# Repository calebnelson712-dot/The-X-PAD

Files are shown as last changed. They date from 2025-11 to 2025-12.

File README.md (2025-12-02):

# The-X-PAD
A  Seeed Studio XIAO RP2040 based macropad within 100 by 100

X-PAD is a custom macropad that has:

- 16 Hotswappable, MX Style Keys
- Per-key SK6812 RGB Baclight
- Based off of the Seeed Studio XIAO RP2040
- 2 Rotary Encoders
- 0.91" OLED Display
- Customizable Firmware
- A custom 3D-Printed Case
- And more!

------ 

# Images

## PCB


## Schematic






## 3D CAD
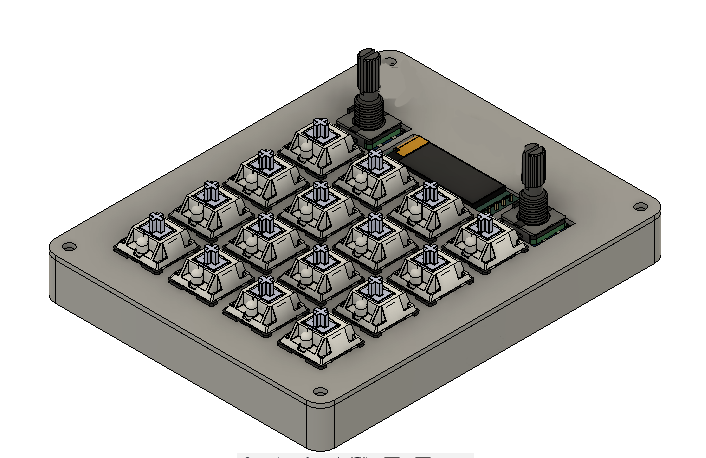
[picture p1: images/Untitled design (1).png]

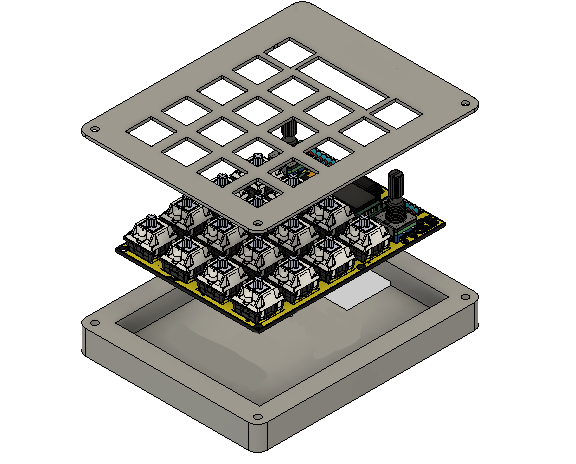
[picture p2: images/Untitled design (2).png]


# Bill Of Materials
Here's the BOM for my macropad:
| Name | Quantity |
|--- |---|
| Seeed Studio XIAO RP2040 | 1 |
| MCP23017 I2C I/O Expander | 1 |
| BSS138 MOSFET | 1 |
| 1N4148 Diode (Through-hole) | 16 |
| MX-Style Switch | 16 |
| Kailh MX-Style Hotswap Socket | 16 |
| Blank DSA Keycap (White) | 16 |
| EC11 With Switch | 2 |
| SK6812 MINI-E RGB LED | 16 |
| 0.1uF 0805 Ceramic Capacitor | 16 |
| 10kΩ 0805 Resistor | 4 |
| 0.91" OLED I2C Display | 1 |
| M3x16mm Screw | - |
| M3x5mx4mm Heatset Insert | - |
| 3D Printed Case (2 Parts) | 1 |
| Main PCB | MOQ: 5 |

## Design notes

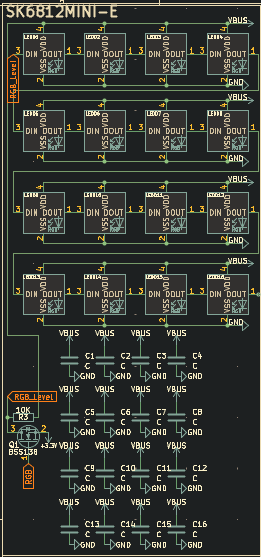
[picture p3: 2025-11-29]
images/RGB.png

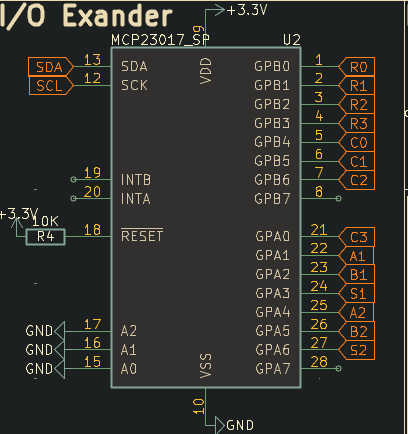
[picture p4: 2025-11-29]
images/Expander.png

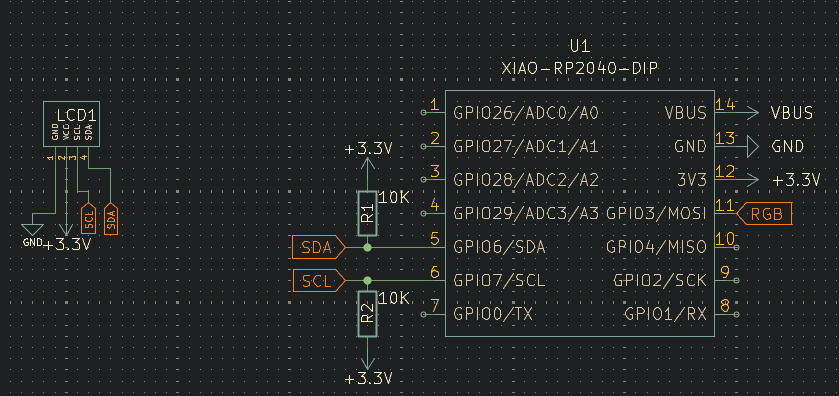
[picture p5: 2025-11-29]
images/OLED and XIAO.png

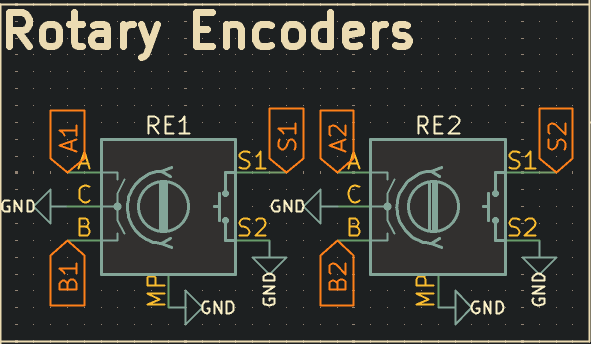
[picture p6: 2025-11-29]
images/Encoders.png

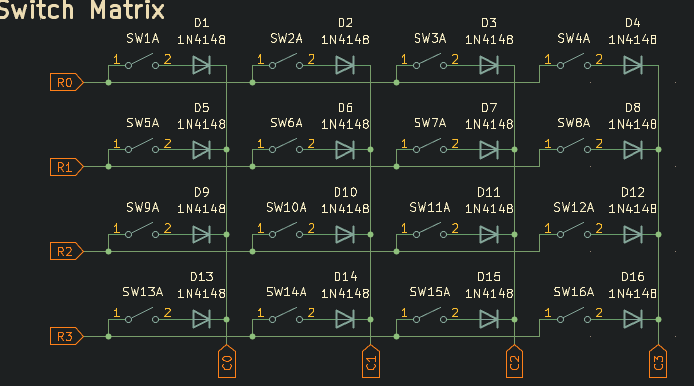
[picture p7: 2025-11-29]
images/Switch Matrix.png

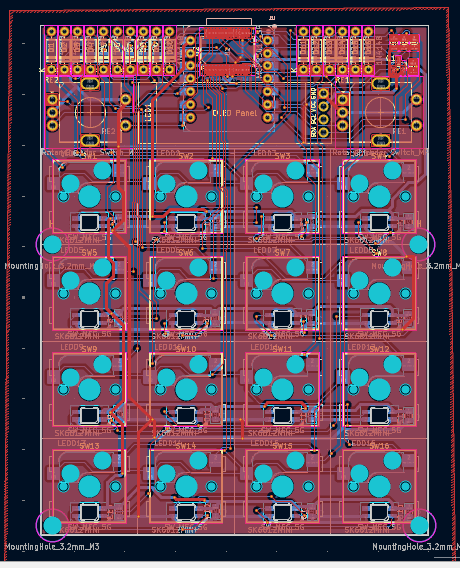
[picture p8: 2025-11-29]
images/PCB.png

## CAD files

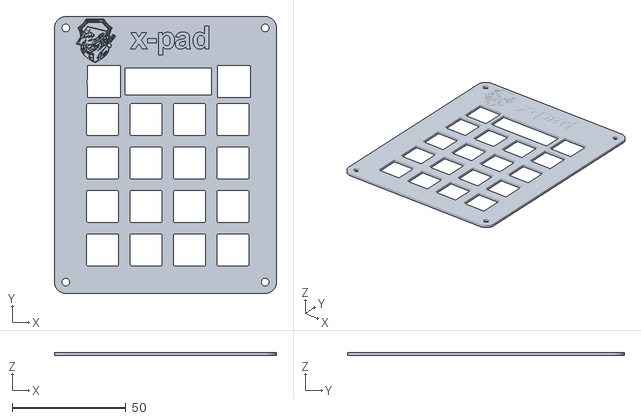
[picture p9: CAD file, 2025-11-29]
CASE/Top OF X-PAD.stl
97.4 x 121.5 x 1.50

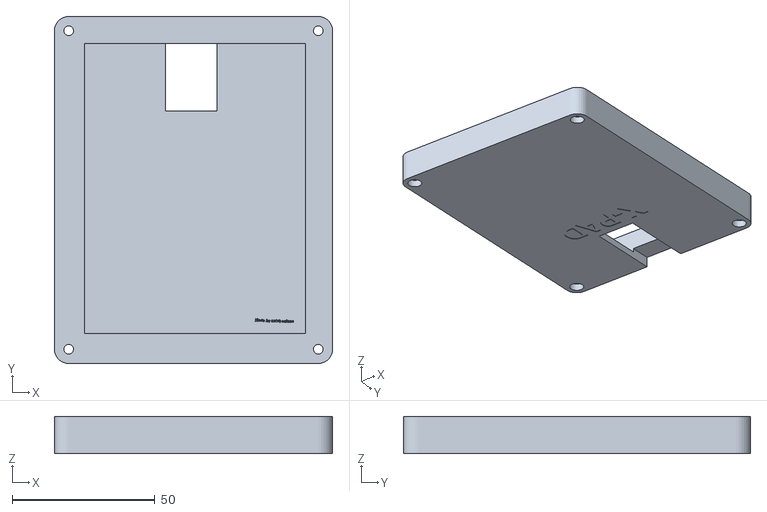
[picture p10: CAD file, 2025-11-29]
CASE/Bottom of x-pad.stl
97.4 x 121.5 x 13.0

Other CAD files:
production/Top of x-pad.step.step
production/Bottom of x-pad.step.step

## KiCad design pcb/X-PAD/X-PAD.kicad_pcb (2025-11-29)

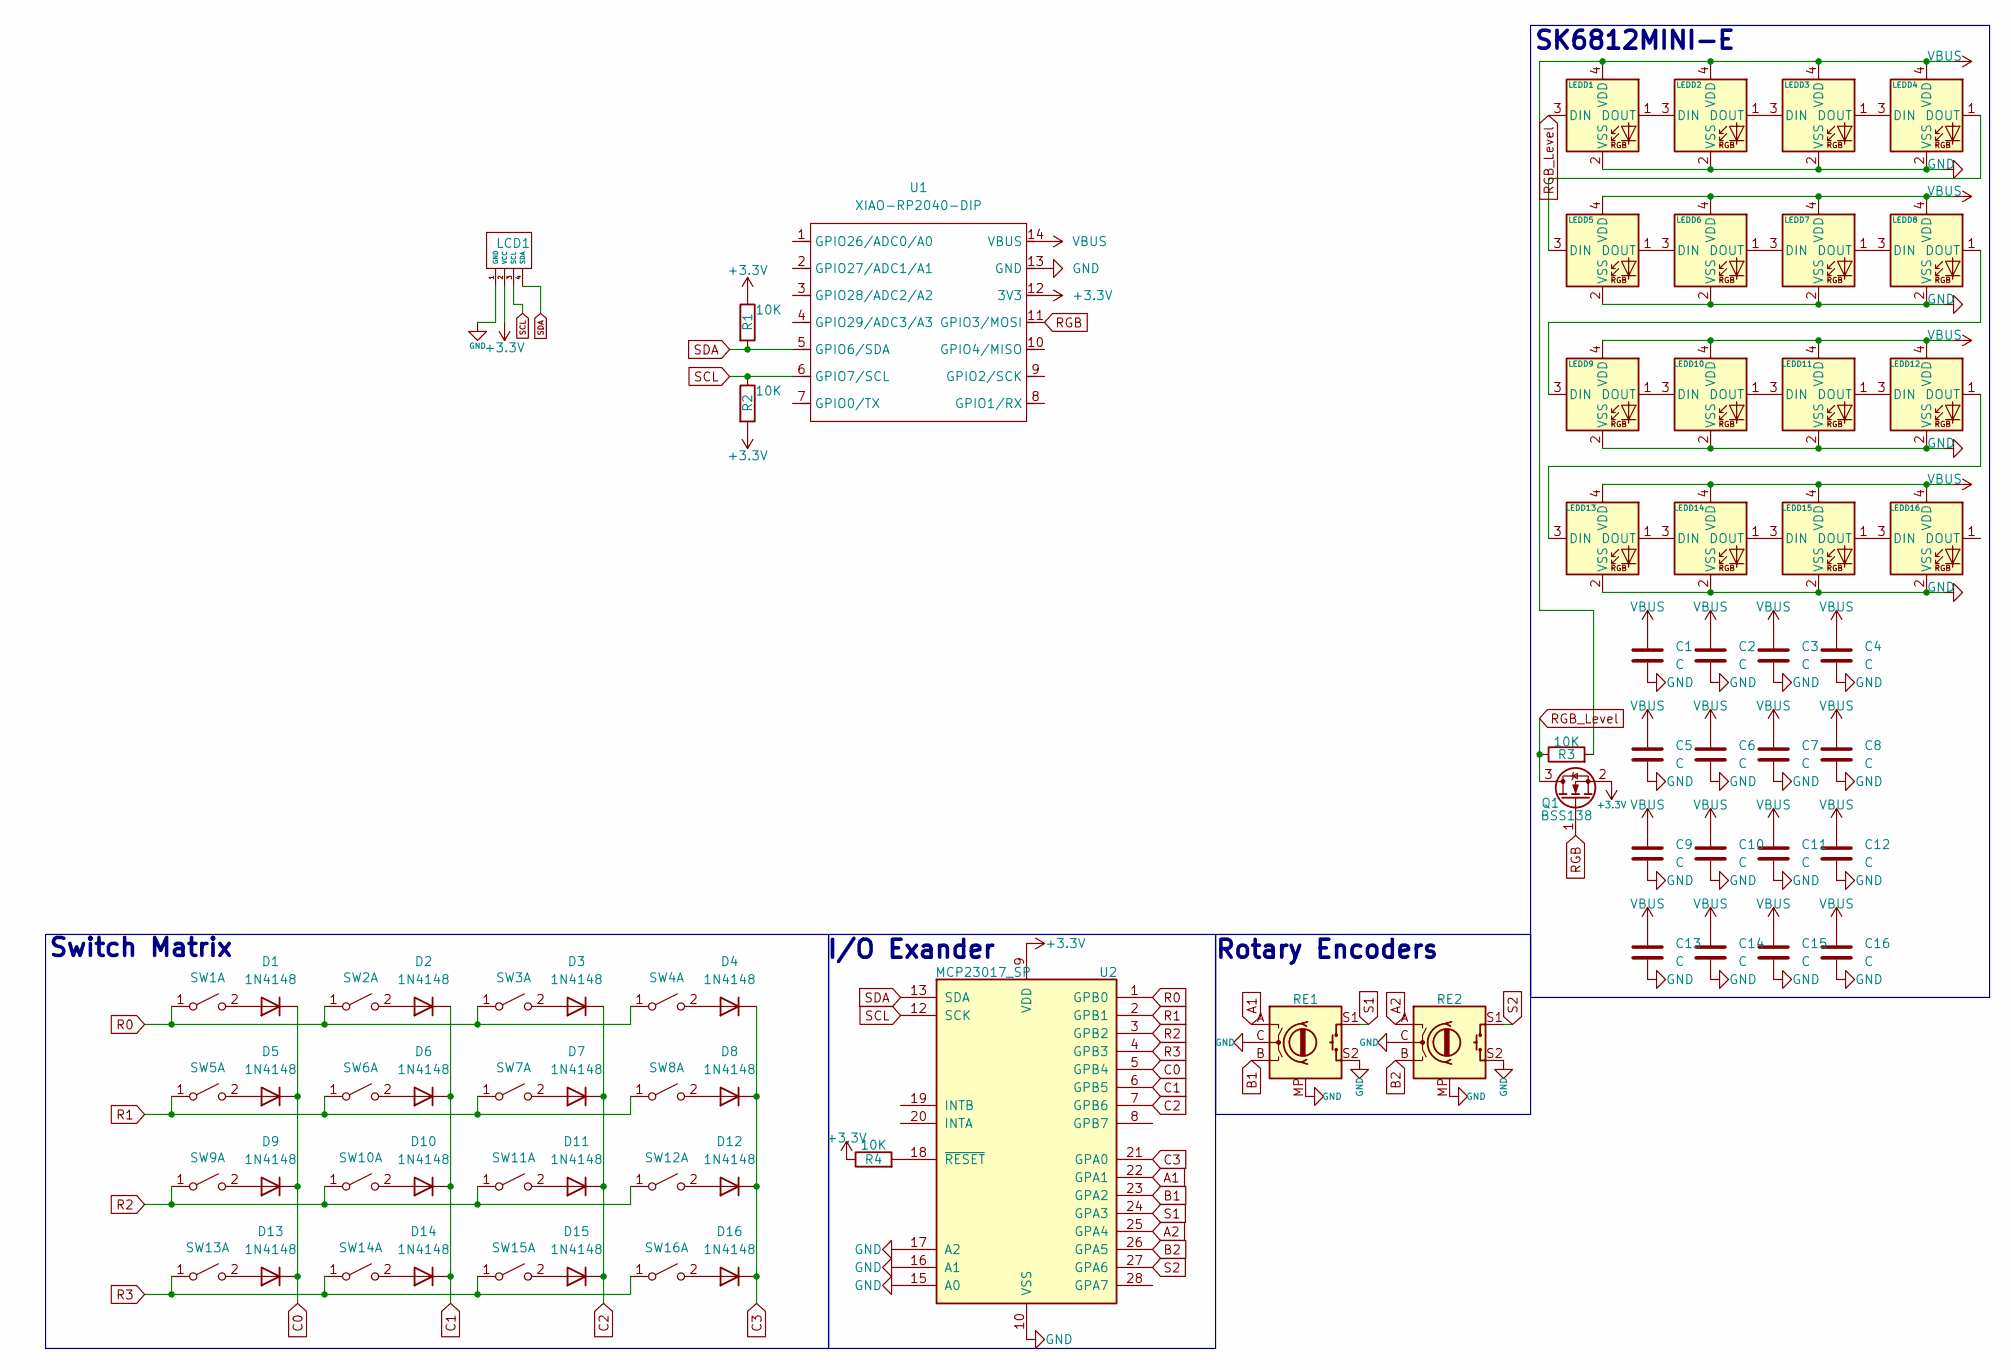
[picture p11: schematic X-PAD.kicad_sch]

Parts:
C1, C2, C3, C4, C5, C6, C7, C8, C9, C10, C11, C12, C13, C14, C15, C16: C; C_0805_2012Metric
D1, D2, D3, D4, D5, D6, D7, D8, D9, D10, D11, D12, D13, D14, D15, D16: 1N4148; D_DO-35_SOD27_P7.62mm_Horizontal
LCD1: SSD1306-0.91-OLED-4pin-128x32
LEDD1, LEDD2, LEDD3, LEDD4, LEDD5, LEDD6, LEDD7, LEDD8, LEDD9, LEDD10, LEDD11, LEDD12, LEDD13, LEDD14, LEDD15, LEDD16: SK6812MINI; MX_SK6812MINI-E
Q1: BSS138; SOT-23
R1, R2, R3, R4: 10K; R_0805_2012Metric
RE1, RE2: RotaryEncoder_Switch_MP; RotaryEncoder_Alps_EC11E-Switch_Vertical_H20mm
SW1, SW2, SW3, SW4, SW5, SW6, SW7, SW8, SW9, SW10, SW11, SW12, SW13, SW14, SW15, SW16: SW_MEC_5G; SW_Hotswap_Kailh_MX_1.00u
U1: XIAO-RP2040-DIP
U2: MCP23017_SP; SSOP-28_5.3x10.2mm_P0.65mm

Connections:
+3.3V: LCD1.2 (VCC), Q1.2 (S), R1.1, R2.2, R4.1, U1.12 (3V3), U2.9 (VDD)
A1: RE1.A, U2.22 (GPA1)
A2: RE2.A, U2.25 (GPA4)
B1: RE1.B, U2.23 (GPA2)
B2: RE2.B, U2.26 (GPA5)
C0: D1.1 (K), D5.1 (K), D9.1 (K), D13.1 (K), U2.5 (GPB4)
C1: D2.1 (K), D6.1 (K), D10.1 (K), D14.1 (K), U2.6 (GPB5)
C2: D3.1 (K), D7.1 (K), D11.1 (K), D15.1 (K), U2.7 (GPB6)
C3: D4.1 (K), D8.1 (K), D12.1 (K), D16.1 (K), U2.21 (GPA0)
GND: C1.2, C2.2, C3.2, C4.2, C5.2, C6.2, C7.2, C8.2, C9.2, C10.2, C11.2, C12.2, C13.2, C14.2, C15.2, C16.2, LCD1.1 (GND), LEDD1.2 (VSS), LEDD2.2 (VSS), LEDD3.2 (VSS), LEDD4.2 (VSS), LEDD5.2 (VSS), LEDD6.2 (VSS), LEDD7.2 (VSS), LEDD8.2 (VSS), LEDD9.2 (VSS), LEDD10.2 (VSS), LEDD11.2 (VSS), LEDD12.2 (VSS), LEDD13.2 (VSS), LEDD14.2 (VSS), LEDD15.2 (VSS), LEDD16.2 (VSS), RE1.C, RE1.MP, RE1.S2, RE2.C, RE2.MP, RE2.S2, U1.13 (GND), U2.10 (VSS), U2.15 (A0), U2.16 (A1), U2.17 (A2)
unnamed: D1.2 (A), SW1.2 (B)
unnamed: D2.2 (A), SW2.2 (B)
unnamed: D3.2 (A), SW3.2 (B)
unnamed: D4.2 (A), SW4.2 (B)
unnamed: D5.2 (A), SW5.2 (B)
unnamed: D6.2 (A), SW6.2 (B)
unnamed: D7.2 (A), SW7.2 (B)
unnamed: D8.2 (A), SW8.2 (B)
unnamed: D9.2 (A), SW9.2 (B)
unnamed: D10.2 (A), SW10.2 (B)
unnamed: D11.2 (A), SW11.2 (B)
unnamed: D12.2 (A), SW12.2 (B)
unnamed: D13.2 (A), SW13.2 (B)
unnamed: D14.2 (A), SW14.2 (B)
unnamed: D15.2 (A), SW15.2 (B)
unnamed: D16.2 (A), SW16.2 (B)
unnamed: LEDD1.1 (DOUT), LEDD2.3 (DIN)
unnamed: LEDD2.1 (DOUT), LEDD3.3 (DIN)
unnamed: LEDD3.1 (DOUT), LEDD4.3 (DIN)
unnamed: LEDD4.1 (DOUT), LEDD5.3 (DIN)
unnamed: LEDD5.1 (DOUT), LEDD6.3 (DIN)
unnamed: LEDD6.1 (DOUT), LEDD7.3 (DIN)
unnamed: LEDD7.1 (DOUT), LEDD8.3 (DIN)
unnamed: LEDD8.1 (DOUT), LEDD9.3 (DIN)
unnamed: LEDD9.1 (DOUT), LEDD10.3 (DIN)
unnamed: LEDD10.1 (DOUT), LEDD11.3 (DIN)
unnamed: LEDD11.1 (DOUT), LEDD12.3 (DIN)
unnamed: LEDD12.1 (DOUT), LEDD13.3 (DIN)
unnamed: LEDD13.1 (DOUT), LEDD14.3 (DIN)
unnamed: LEDD14.1 (DOUT), LEDD15.3 (DIN)
unnamed: LEDD15.1 (DOUT), LEDD16.3 (DIN)
unnamed: R4.2, U2.18 (~RESET)
R0: SW1.1 (A), SW2.1 (A), SW3.1 (A), SW4.1 (A), U2.1 (GPB0)
R1: SW5.1 (A), SW6.1 (A), SW7.1 (A), SW8.1 (A), U2.2 (GPB1)
R2: SW9.1 (A), SW10.1 (A), SW11.1 (A), SW12.1 (A), U2.3 (GPB2)
R3: SW13.1 (A), SW14.1 (A), SW15.1 (A), SW16.1 (A), U2.4 (GPB3)
RGB: Q1.1 (G), U1.11 (GPIO3/MOSI)
RGB_Level: LEDD1.3 (DIN), Q1.3 (D), R3.1
S1: RE1.S1, U2.24 (GPA3)
S2: RE2.S1, U2.27 (GPA6)
SCL: LCD1.3 (SCL), R2.1, U1.6 (GPIO7/SCL), U2.12 (SCK)
SDA: LCD1.4 (SDA), R1.2, U1.5 (GPIO6/SDA), U2.13 (SDA)
VBUS: C1.1, C2.1, C3.1, C4.1, C5.1, C6.1, C7.1, C8.1, C9.1, C10.1, C11.1, C12.1, C13.1, C14.1, C15.1, C16.1, LEDD1.4 (VDD), LEDD2.4 (VDD), LEDD3.4 (VDD), LEDD4.4 (VDD), LEDD5.4 (VDD), LEDD6.4 (VDD), LEDD7.4 (VDD), LEDD8.4 (VDD), LEDD9.4 (VDD), LEDD10.4 (VDD), LEDD11.4 (VDD), LEDD12.4 (VDD), LEDD13.4 (VDD), LEDD14.4 (VDD), LEDD15.4 (VDD), LEDD16.4 (VDD), R3.2, U1.14 (VBUS)

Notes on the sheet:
Rotary Encoders
I/O Exander
SK6812MINI-E
Switch Matrix

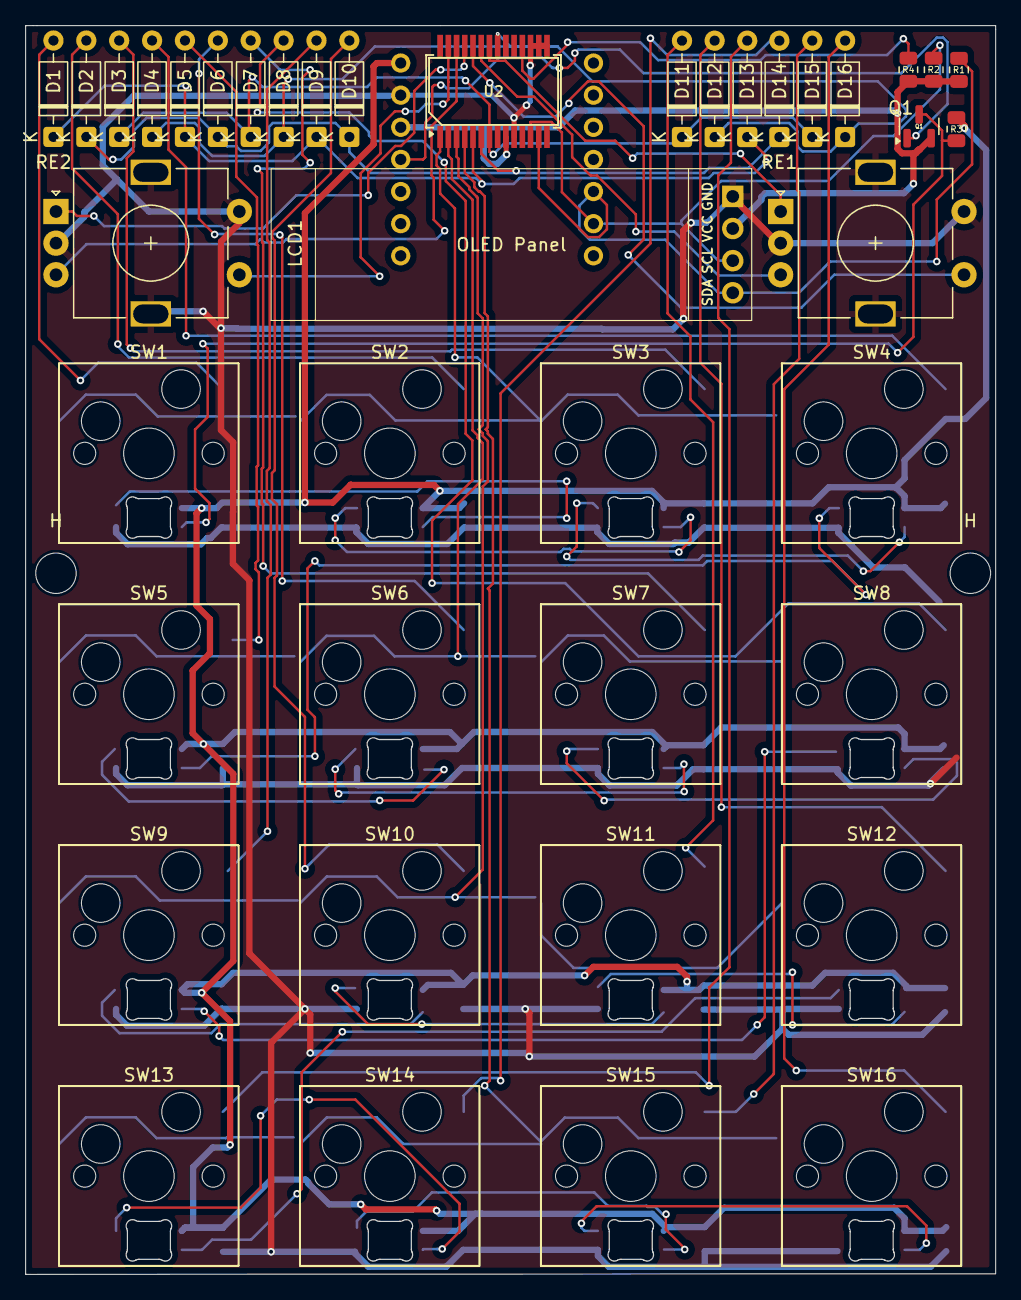
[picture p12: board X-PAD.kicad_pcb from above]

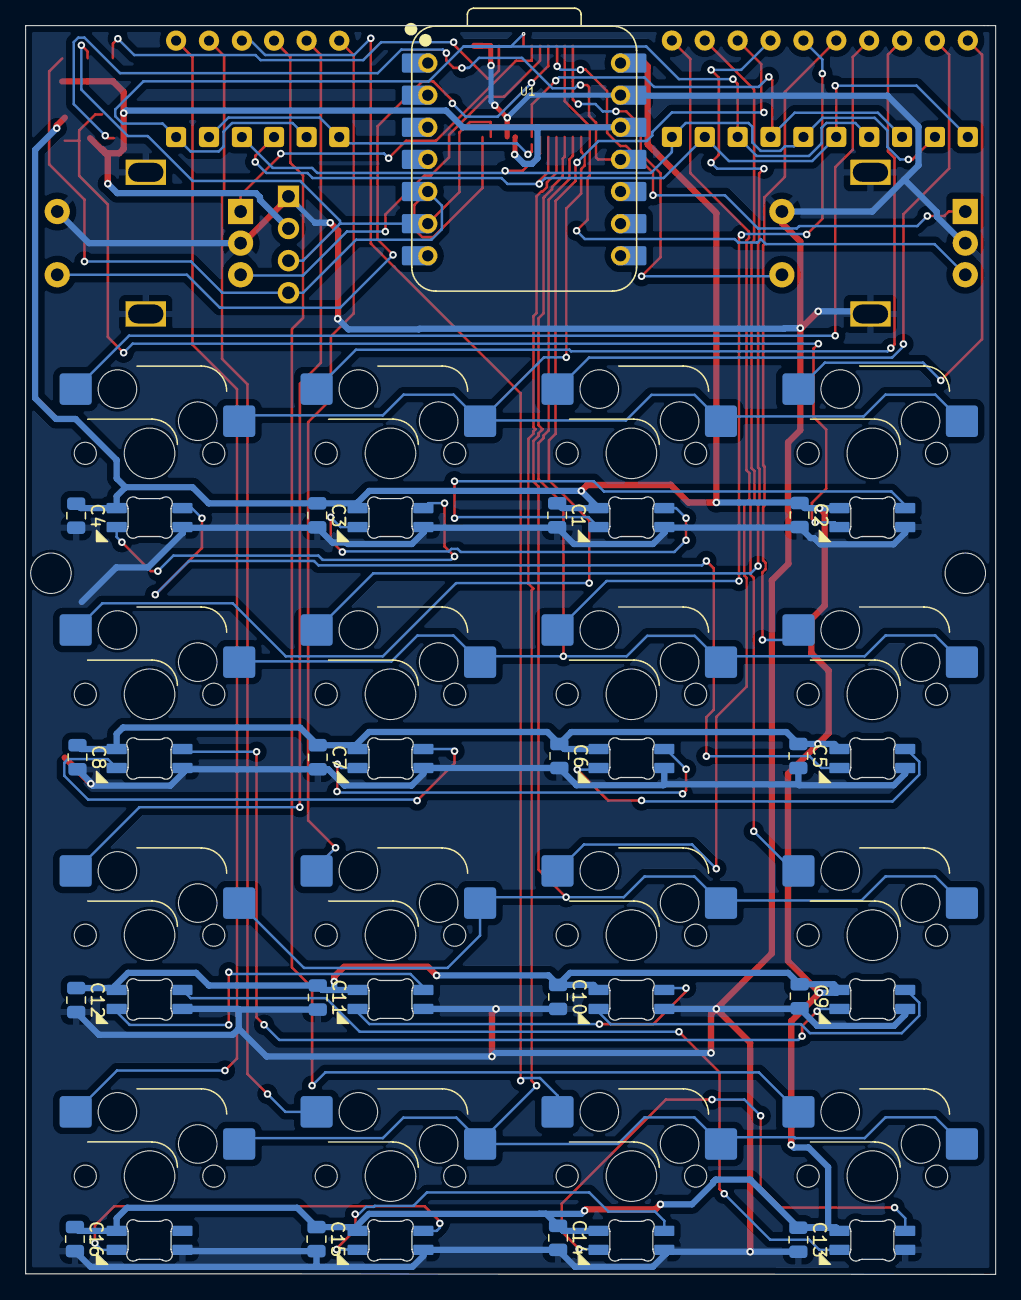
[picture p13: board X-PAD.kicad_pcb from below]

Board: 2 copper layers, 76.7 x 98.7 mm, 76 parts (17 on the bottom side), 53 nets.

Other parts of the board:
H: MountingHole_3.2mm_M3
H#2: MountingHole_3.2mm_M3

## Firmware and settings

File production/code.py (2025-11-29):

import board
import busio
import digitalio
import storage

from kmk.kmk_keyboard import KMKKeyboard
from kmk.matrix import DiodeOrientation
from kmk.scanners import ioexpander
from kmk.handlers.sequences import send_string
from kmk.keys import KC
from kmk.modules.encoder import EncoderHandler
from kmk.modules.layers import Layers
from kmk.modules.rgb import RGB
from kmk.modules.media_keys import MediaKeys
from kmk.extensions.OLED import OLED, OledDisplayMode, OledReactionType

from adafruit_mcp230xx.mcp23017 import MCP23017

# --- I2C setup ---
i2c = busio.I2C(board.GP1, board.GP0)  # SCL: GP1, SDA: GP0 (swap if your wiring is different)
mcp = MCP23017(i2c, address=0x20)

# --- Key matrix setup via MCP23017 ---
# Rows: GPB0-B3, Cols: GPB4-B6, GPA0
ROW_PINS = [8, 9, 10, 11]  # MCP23017 GPB0-GPB3
COL_PINS = [12, 13, 14, 21]  # GPB4-GPB6, GPA0

# --- KMK Keyboard object ---
keyboard = KMKKeyboard()

keyboard.matrix = ioexpander.IOExpanderMatrix(
    mcp,
    row_pins=ROW_PINS,
    col_pins=COL_PINS,
    columns_to_anodes=True,
    diode_orientation=DiodeOrientation.COL2ROW,
)

keyboard.modules.append(Layers())
keyboard.modules.append(MediaKeys())

# --- RGB setup ---
rgb = RGB(pixel_pin=board.GP3, num_pixels=16, val_limit=80, hue_default=0)
keyboard.modules.append(rgb)

# --- OLED setup ---
oled_ext = OLED(
    i2c=i2c,  # Use same I2C bus as MCP23017
    addr=0x3C,
    flip=False,
    display_mode=OledDisplayMode.LAYER,
    timeout=60,
    reaction=OledReactionType.LAYER,
)
keyboard.extensions.append(oled_ext)

# --- Encoder setup (via MCP23017) ---
encoder_handler = EncoderHandler()
# Encoder 1: A1 (22), B1 (23), S1 (24) [GPA1-3]
# Encoder 2: A2 (25), B2 (26), S2 (27) [GPA4-6]
encoder_handler.pins = [
    (22, 23),  # Encoder 1 A/B
    (25, 26),  # Encoder 2 A/B
]
encoder_handler.swpins = [24, 27]  # Encoder 1/2 switch pins (S1/S2)
keyboard.modules.append(encoder_handler)

# --- Keymap ---
# Example multimedia pad layout
keyboard.keymap = [
    [KC.MPLY, KC.MPRV, KC.MNXT, KC.MSTP,
     KC.VOLU, KC.VOLD, KC.MUTE, KC.MUTE,
     KC.FAST_FWD, KC.REWIND, KC.PSCR, KC.CALC,
     KC.NO, KC.NO, KC.NO, KC.NO],
]

# --- Encoder Actions ---
@encoder_handler.handler
def encoder_callback(index, direction):
    if index == 0:
        # Encoder 1: Volume
        if direction == 1:
            keyboard.send(KC.VOLU)
        else:
            keyboard.send(KC.VOLD)
    elif index == 1:
        # Encoder 2: Scroll
        if direction == 1:
            keyboard.send(KC.PGDN)
        else:
            keyboard.send(KC.PGUP)

# Encoder switch actions
@encoder_handler.switch_handler
def encoder_switch_callback(index, pressed):
    if pressed:
        if index == 0:
            # Encoder 1 switch: mute/unmute
            keyboard.send(KC.MUTE)
        elif index == 1:
            # Encoder 2 switch: change RGB layer (cycles through, for demonstration)
            rgb.next_layer()

if __name__ == '__main__':
    keyboard.go()
